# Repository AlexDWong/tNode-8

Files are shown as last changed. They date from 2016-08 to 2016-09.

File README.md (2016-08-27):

# tNode-8

The tNode-8 is an 8-universe ArtNet to DMX output node powered by a Texas Instruments Tiva-C microprocessor (TM4C1294NCPDT) and is currently in development. 

##Features

The tNode-8 is expected to include the following features:
* 8 DMX512 outputs
  * All outputs fused and optically and electrically isolated
  * Full RS485/DMX512 compliance
  * Screw terminals enabling end-user selection of 3-pin or 5-pin connectors
  * Individual universe assignment on each output
* 10/100Mbps Ethernet connectivity
* LCD character display and user input for settings adjustment
* 19"/1U rackmount enclousre
* PowerCON In/Thru
  * Auto-ranging power supply (100-240V, 50/60Hz)   
  * Input fuse

Potential features for future revisions may include (but are not limited to):
* DMX input capability
* Remote Device Management (RDM)
* Remote node configuration (LAN-based)
* Physical lockout switch
* Expansion to 16 universes of DMX I/O

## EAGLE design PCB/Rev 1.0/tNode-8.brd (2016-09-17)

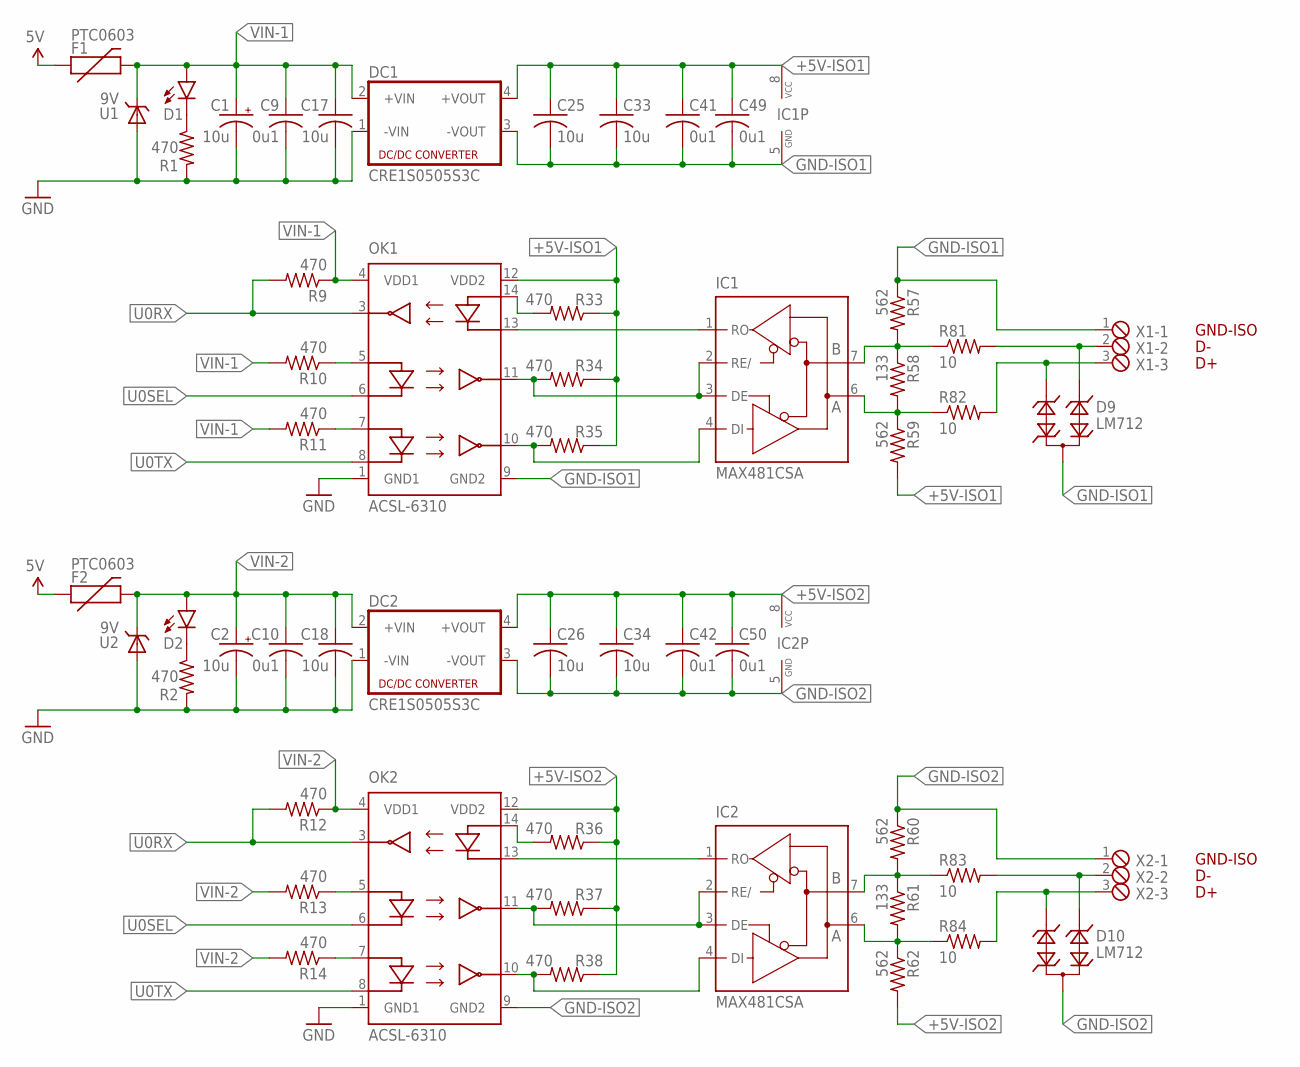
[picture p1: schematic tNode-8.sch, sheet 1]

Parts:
C1, C2: 10u; E2,5-5-NOSILK
C9, C10, C41, C42, C49, C50: 0u1; C0603K
C17, C18, C25, C26, C33, C34: 10u; C0603K
D1, D2: LED0603; LED-0603
D9, D10: LM712; SOT23
DC1, DC2: CRE1S0505S3C; 4SIL
F1, F2: PTC0603; 0603
IC1, IC2: MAX481CSA; SO08
OK1, OK2: ACSL-6310; SO-16
R1, R2, R9, R10, R11, R12, R13, R14, R33, R34, R35, R36, R37, R38: 470; R0603
R57, R59, R60, R62: 562; R0603
R58, R61: 133; R0603
R81, R82, R83, R84: 10; R0603
U1, U2: 9V; SOD323-NOSILK
X1, X2: MPT3; 3POL254

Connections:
5V: F1.1, F2.1; also elsewhere on the board
+5V-ISO1: C25.1, C33.1, C41.1, C49.1, DC1.4 (+VOUT), IC1.8 (VCC), OK1.12 (VDD2), R33.1, R34.1, R35.1, R59.2
+5V-ISO2: C26.1, C34.1, C42.1, C50.1, DC2.4 (+VOUT), IC2.8 (VCC), OK2.12 (VDD2), R36.1, R37.1, R38.1, R62.2
GND: C1.-, C2.-, C9.2, C10.2, C17.2, C18.2, DC1.1 (-VIN), DC2.1 (-VIN), OK1.1 (GND1), OK2.1 (GND1), R1.2, R2.2, U1.A, U2.A; also elsewhere on the board
GND-ISO1: C25.2, C33.2, C41.2, C49.2, D9.3, DC1.3 (-VOUT), IC1.5 (GND), OK1.9 (GND2), R57.1, X1.1
GND-ISO2: C26.2, C34.2, C42.2, C50.2, D10.3, DC2.3 (-VOUT), IC2.5 (GND), OK2.9 (GND2), R60.1, X2.1
unnamed: IC2.7 (B), R60.2, R61.1, R83.1
unnamed: IC1.7 (B), R57.2, R58.1, R81.1
unnamed: IC1.6 (A), R58.2, R59.1, R82.1
unnamed: IC2.6 (A), R61.2, R62.1, R84.1
unnamed: IC2.1 (RO), OK2.13 (C3)
unnamed: IC2.2 (RE/), IC2.3 (DE), OK2.11 (VO1), R37.2
unnamed: OK2.5 (A1), R13.1
unnamed: OK2.7 (A2), R14.1
unnamed: OK2.14 (A3), R36.2
unnamed: IC1.1 (RO), OK1.13 (C3)
unnamed: D2.C, R2.1
unnamed: D10.1, R83.2, X2.2
unnamed: D10.2, R84.2, X2.3
unnamed: IC1.2 (RE/), IC1.3 (DE), OK1.11 (VO1), R34.2
unnamed: OK1.5 (A1), R10.1
unnamed: OK1.7 (A2), R11.1
unnamed: OK1.14 (A3), R33.2
unnamed: D1.C, R1.1
unnamed: D9.1, R81.2, X1.2
unnamed: D9.2, R82.2, X1.3
OPTO-OUT1: IC1.4 (DI), OK1.10 (VO2), R35.2
OPTO-OUT2: IC2.4 (DI), OK2.10 (VO2), R38.2
U0RX: OK1.3 (V03), OK2.3 (V03), R9.2, R12.2; also elsewhere on the board
U0SEL: OK1.6 (C1), OK2.6 (C1); also elsewhere on the board
U0TX: OK1.8 (C2), OK2.8 (C2); also elsewhere on the board
VIN-1: C1.+, C9.1, C17.1, D1.A, DC1.2 (+VIN), F1.2, OK1.4 (VDD1), R9.1, R10.2, R11.2, U1.C
VIN-2: C2.+, C10.1, C18.1, D2.A, DC2.2 (+VIN), F2.2, OK2.4 (VDD1), R12.1, R13.2, R14.2, U2.C

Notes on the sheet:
GND-ISO

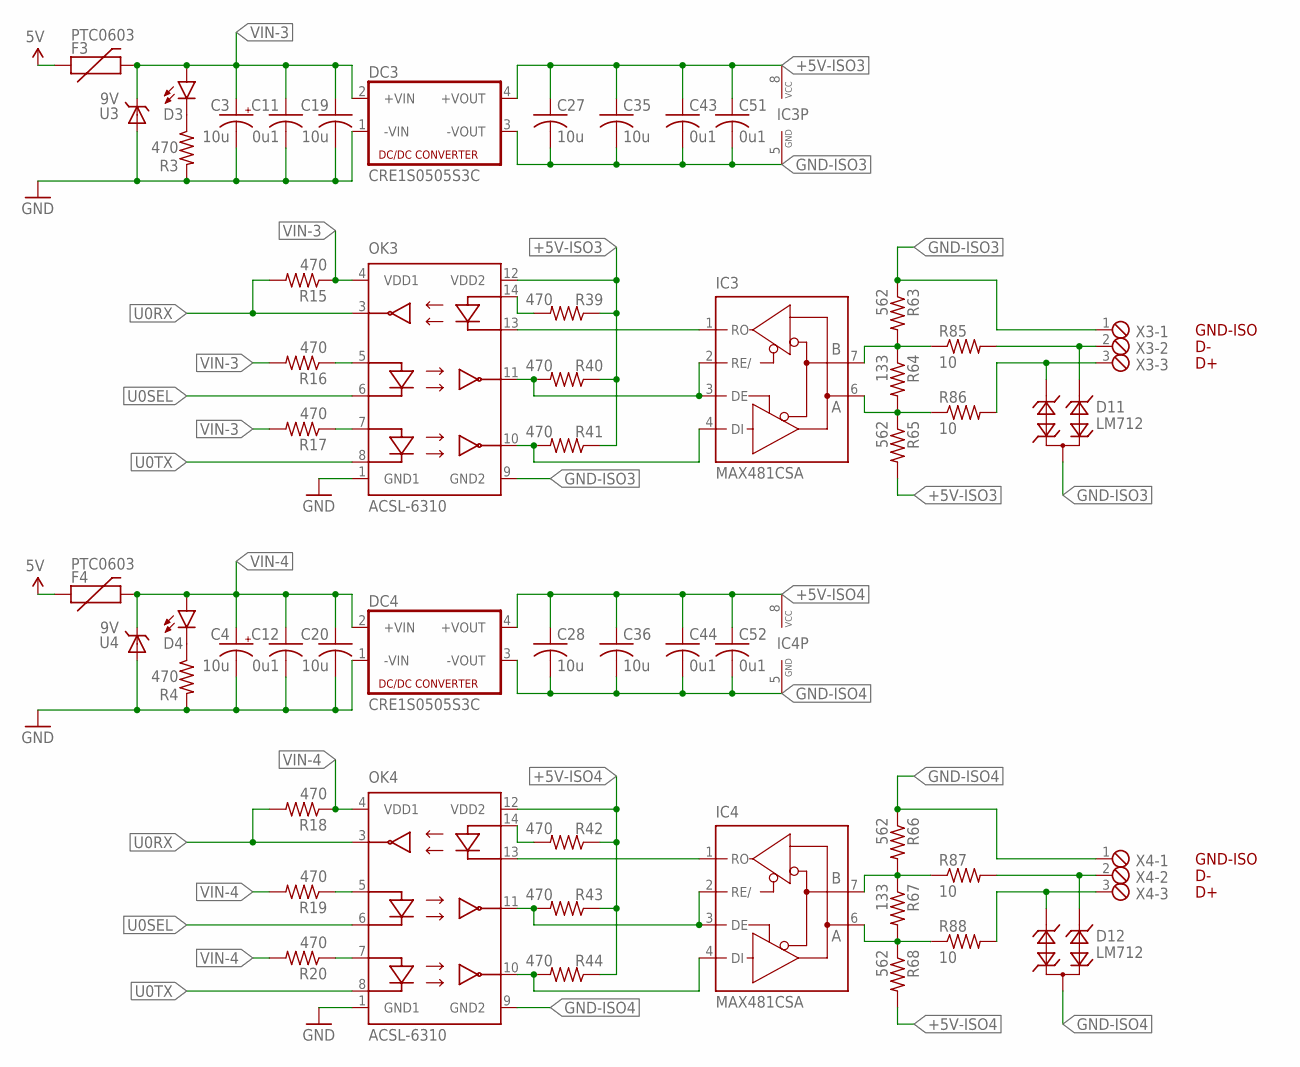
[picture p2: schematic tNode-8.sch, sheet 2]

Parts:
C3, C4: 10u; E2,5-5-NOSILK
C11, C12, C43, C44, C51, C52: 0u1; C0603K
C19, C20, C27, C28, C35, C36: 10u; C0603K
D3, D4: LED0603; LED-0603
D11, D12: LM712; SOT23
DC3, DC4: CRE1S0505S3C; 4SIL
F3, F4: PTC0603; 0603
IC3, IC4: MAX481CSA; SO08
OK3, OK4: ACSL-6310; SO-16
R3, R4, R15, R16, R17, R18, R19, R20, R39, R40, R41, R42, R43, R44: 470; R0603
R63, R65, R66, R68: 562; R0603
R64, R67: 133; R0603
R85, R86, R87, R88: 10; R0603
U3, U4: 9V; SOD323-NOSILK
X3, X4: MPT3; 3POL254

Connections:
5V: F3.1, F4.1; also elsewhere on the board
+5V-ISO3: C27.1, C35.1, C43.1, C51.1, DC3.4 (+VOUT), IC3.8 (VCC), OK3.12 (VDD2), R39.1, R40.1, R41.1, R65.2
+5V-ISO4: C28.1, C36.1, C44.1, C52.1, DC4.4 (+VOUT), IC4.8 (VCC), OK4.12 (VDD2), R42.1, R43.1, R44.1, R68.2
GND: C3.-, C4.-, C11.2, C12.2, C19.2, C20.2, DC3.1 (-VIN), DC4.1 (-VIN), OK3.1 (GND1), OK4.1 (GND1), R3.2, R4.2, U3.A, U4.A; also elsewhere on the board
GND-ISO3: C27.2, C35.2, C43.2, C51.2, D11.3, DC3.3 (-VOUT), IC3.5 (GND), OK3.9 (GND2), R63.1, X3.1
GND-ISO4: C28.2, C36.2, C44.2, C52.2, D12.3, DC4.3 (-VOUT), IC4.5 (GND), OK4.9 (GND2), R66.1, X4.1
unnamed: IC3.7 (B), R63.2, R64.1, R85.1
unnamed: IC3.6 (A), R64.2, R65.1, R86.1
unnamed: IC3.1 (RO), OK3.13 (C3)
unnamed: IC3.2 (RE/), IC3.3 (DE), OK3.11 (VO1), R40.2
unnamed: OK3.5 (A1), R16.1
unnamed: OK3.7 (A2), R17.1
unnamed: OK3.14 (A3), R39.2
unnamed: D3.C, R3.1
unnamed: D11.1, R85.2, X3.2
unnamed: D11.2, R86.2, X3.3
unnamed: IC4.7 (B), R66.2, R67.1, R87.1
unnamed: IC4.6 (A), R67.2, R68.1, R88.1
unnamed: IC4.1 (RO), OK4.13 (C3)
unnamed: IC4.2 (RE/), IC4.3 (DE), OK4.11 (VO1), R43.2
unnamed: OK4.5 (A1), R19.1
unnamed: OK4.7 (A2), R20.1
unnamed: OK4.14 (A3), R42.2
unnamed: D4.C, R4.1
unnamed: D12.1, R87.2, X4.2
unnamed: D12.2, R88.2, X4.3
OPTO-OUT3: IC3.4 (DI), OK3.10 (VO2), R41.2
OPTO-OUT4: IC4.4 (DI), OK4.10 (VO2), R44.2
U0RX: OK3.3 (V03), OK4.3 (V03), R15.2, R18.2; also elsewhere on the board
U0SEL: OK3.6 (C1), OK4.6 (C1); also elsewhere on the board
U0TX: OK3.8 (C2), OK4.8 (C2); also elsewhere on the board
VIN-3: C3.+, C11.1, C19.1, D3.A, DC3.2 (+VIN), F3.2, OK3.4 (VDD1), R15.1, R16.2, R17.2, U3.C
VIN-4: C4.+, C12.1, C20.1, D4.A, DC4.2 (+VIN), F4.2, OK4.4 (VDD1), R18.1, R19.2, R20.2, U4.C

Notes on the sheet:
GND-ISO

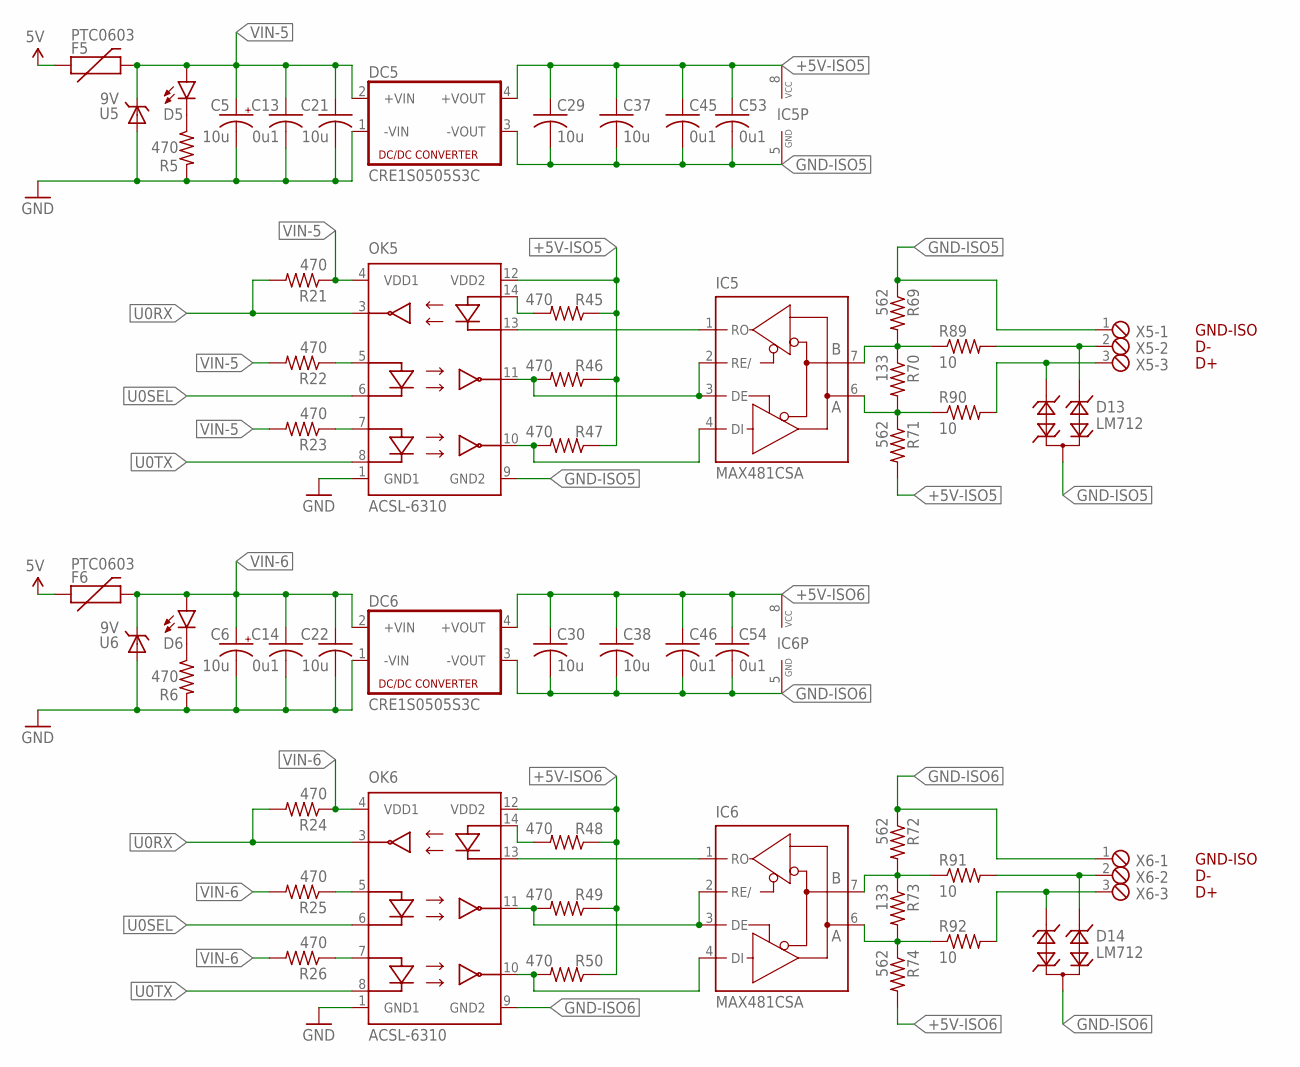
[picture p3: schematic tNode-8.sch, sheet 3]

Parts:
C5, C6: 10u; E2,5-5-NOSILK
C13, C14, C45, C46, C53, C54: 0u1; C0603K
C21, C22, C29, C30, C37, C38: 10u; C0603K
D5, D6: LED0603; LED-0603
D13, D14: LM712; SOT23
DC5, DC6: CRE1S0505S3C; 4SIL
F5, F6: PTC0603; 0603
IC5, IC6: MAX481CSA; SO08
OK5, OK6: ACSL-6310; SO-16
R5, R6, R21, R22, R23, R24, R25, R26, R45, R46, R47, R48, R49, R50: 470; R0603
R69, R71, R72, R74: 562; R0603
R70, R73: 133; R0603
R89, R90, R91, R92: 10; R0603
U5, U6: 9V; SOD323-NOSILK
X5, X6: MPT3; 3POL254

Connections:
5V: F5.1, F6.1; also elsewhere on the board
+5V-ISO5: C29.1, C37.1, C45.1, C53.1, DC5.4 (+VOUT), IC5.8 (VCC), OK5.12 (VDD2), R45.1, R46.1, R47.1, R71.2
+5V-ISO6: C30.1, C38.1, C46.1, C54.1, DC6.4 (+VOUT), IC6.8 (VCC), OK6.12 (VDD2), R48.1, R49.1, R50.1, R74.2
GND: C5.-, C6.-, C13.2, C14.2, C21.2, C22.2, DC5.1 (-VIN), DC6.1 (-VIN), OK5.1 (GND1), OK6.1 (GND1), R5.2, R6.2, U5.A, U6.A; also elsewhere on the board
GND-ISO5: C29.2, C37.2, C45.2, C53.2, D13.3, DC5.3 (-VOUT), IC5.5 (GND), OK5.9 (GND2), R69.1, X5.1
GND-ISO6: C30.2, C38.2, C46.2, C54.2, D14.3, DC6.3 (-VOUT), IC6.5 (GND), OK6.9 (GND2), R72.1, X6.1
unnamed: IC5.7 (B), R69.2, R70.1, R89.1
unnamed: IC5.6 (A), R70.2, R71.1, R90.1
unnamed: IC5.1 (RO), OK5.13 (C3)
unnamed: IC5.2 (RE/), IC5.3 (DE), OK5.11 (VO1), R46.2
unnamed: OK5.5 (A1), R22.1
unnamed: OK5.7 (A2), R23.1
unnamed: OK5.14 (A3), R45.2
unnamed: D5.C, R5.1
unnamed: D13.1, R89.2, X5.2
unnamed: D13.2, R90.2, X5.3
unnamed: IC6.7 (B), R72.2, R73.1, R91.1
unnamed: IC6.6 (A), R73.2, R74.1, R92.1
unnamed: IC6.1 (RO), OK6.13 (C3)
unnamed: IC6.2 (RE/), IC6.3 (DE), OK6.11 (VO1), R49.2
unnamed: OK6.5 (A1), R25.1
unnamed: OK6.7 (A2), R26.1
unnamed: OK6.14 (A3), R48.2
unnamed: D6.C, R6.1
unnamed: D14.1, R91.2, X6.2
unnamed: D14.2, R92.2, X6.3
OPTO-OUT5: IC5.4 (DI), OK5.10 (VO2), R47.2
OPTO-OUT6: IC6.4 (DI), OK6.10 (VO2), R50.2
U0RX: OK5.3 (V03), OK6.3 (V03), R21.2, R24.2; also elsewhere on the board
U0SEL: OK5.6 (C1), OK6.6 (C1); also elsewhere on the board
U0TX: OK5.8 (C2), OK6.8 (C2); also elsewhere on the board
VIN-5: C5.+, C13.1, C21.1, D5.A, DC5.2 (+VIN), F5.2, OK5.4 (VDD1), R21.1, R22.2, R23.2, U5.C
VIN-6: C6.+, C14.1, C22.1, D6.A, DC6.2 (+VIN), F6.2, OK6.4 (VDD1), R24.1, R25.2, R26.2, U6.C

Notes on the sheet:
GND-ISO

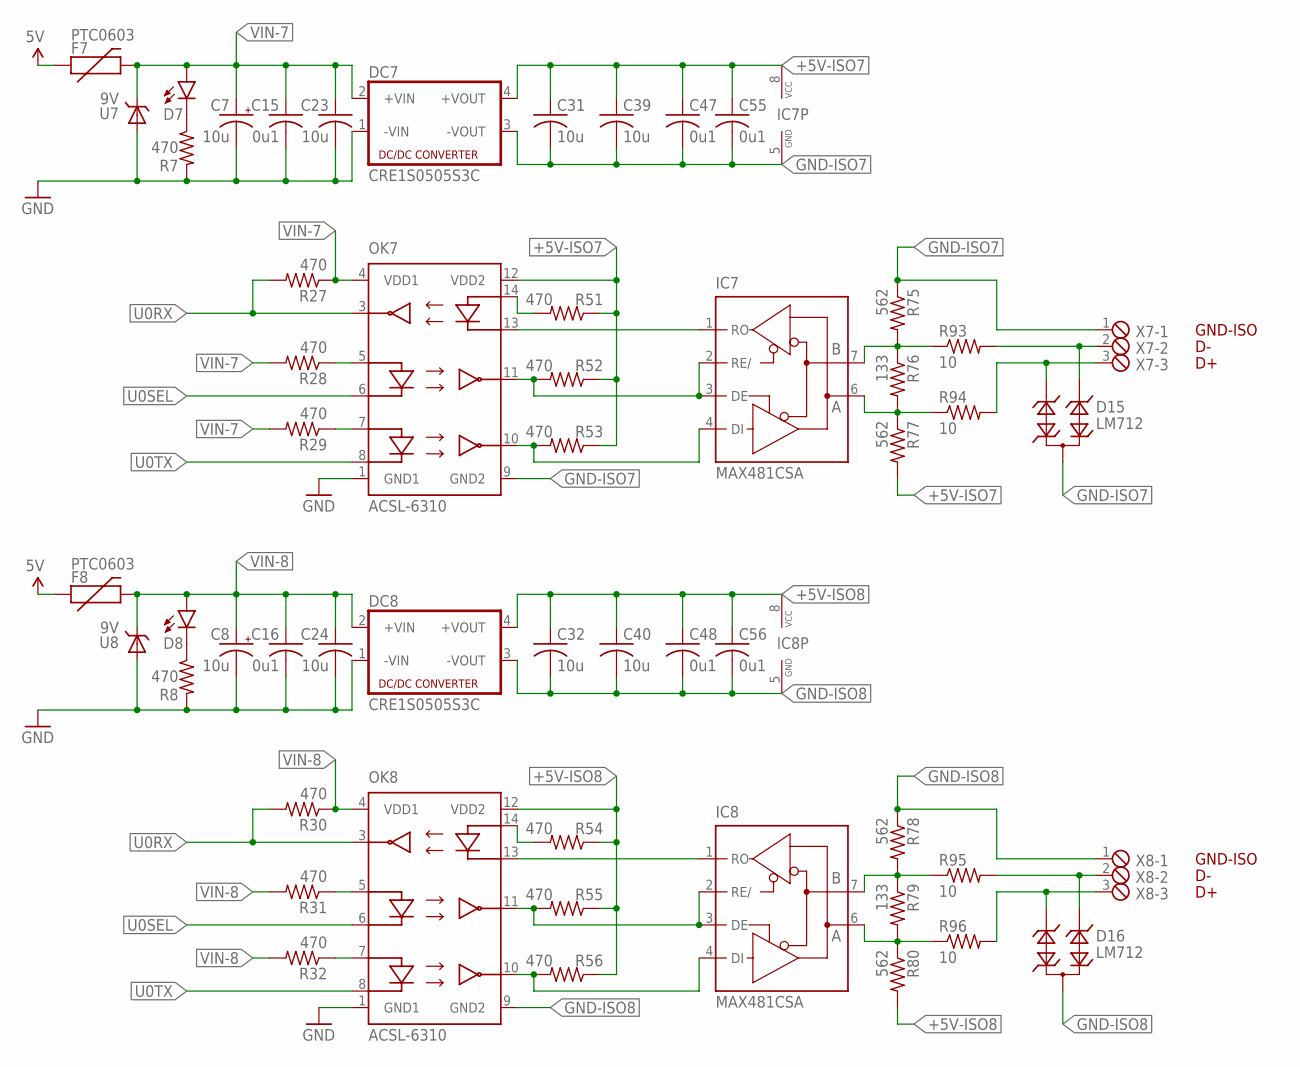
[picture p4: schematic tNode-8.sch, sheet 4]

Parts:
C7, C8: 10u; E2,5-5-NOSILK
C15, C16, C47, C48, C55, C56: 0u1; C0603K
C23, C24, C31, C32, C39, C40: 10u; C0603K
D7, D8: LED0603; LED-0603
D15, D16: LM712; SOT23
DC7, DC8: CRE1S0505S3C; 4SIL
F7, F8: PTC0603; 0603
IC7, IC8: MAX481CSA; SO08
OK7, OK8: ACSL-6310; SO-16
R7, R8, R27, R28, R29, R30, R31, R32, R51, R52, R53, R54, R55, R56: 470; R0603
R75, R77, R78, R80: 562; R0603
R76, R79: 133; R0603
R93, R94, R95, R96: 10; R0603
U7, U8: 9V; SOD323-NOSILK
X7, X8: MPT3; 3POL254

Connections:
5V: F7.1, F8.1; also elsewhere on the board
+5V-ISO7: C31.1, C39.1, C47.1, C55.1, DC7.4 (+VOUT), IC7.8 (VCC), OK7.12 (VDD2), R51.1, R52.1, R53.1, R77.2
+5V-ISO8: C32.1, C40.1, C48.1, C56.1, DC8.4 (+VOUT), IC8.8 (VCC), OK8.12 (VDD2), R54.1, R55.1, R56.1, R80.2
GND: C7.-, C8.-, C15.2, C16.2, C23.2, C24.2, DC7.1 (-VIN), DC8.1 (-VIN), OK7.1 (GND1), OK8.1 (GND1), R7.2, R8.2, U7.A, U8.A; also elsewhere on the board
GND-ISO7: C31.2, C39.2, C47.2, C55.2, D15.3, DC7.3 (-VOUT), IC7.5 (GND), OK7.9 (GND2), R75.1, X7.1
GND-ISO8: C32.2, C40.2, C48.2, C56.2, D16.3, DC8.3 (-VOUT), IC8.5 (GND), OK8.9 (GND2), R78.1, X8.1
unnamed: IC7.7 (B), R75.2, R76.1, R93.1
unnamed: IC7.6 (A), R76.2, R77.1, R94.1
unnamed: IC7.1 (RO), OK7.13 (C3)
unnamed: IC7.2 (RE/), IC7.3 (DE), OK7.11 (VO1), R52.2
unnamed: OK7.5 (A1), R28.1
unnamed: OK7.7 (A2), R29.1
unnamed: OK7.14 (A3), R51.2
unnamed: D7.C, R7.1
unnamed: D15.1, R93.2, X7.2
unnamed: D15.2, R94.2, X7.3
unnamed: IC8.7 (B), R78.2, R79.1, R95.1
unnamed: IC8.6 (A), R79.2, R80.1, R96.1
unnamed: IC8.1 (RO), OK8.13 (C3)
unnamed: IC8.2 (RE/), IC8.3 (DE), OK8.11 (VO1), R55.2
unnamed: OK8.5 (A1), R31.1
unnamed: OK8.7 (A2), R32.1
unnamed: OK8.14 (A3), R54.2
unnamed: D8.C, R8.1
unnamed: D16.1, R95.2, X8.2
unnamed: D16.2, R96.2, X8.3
OPTO-OUT7: IC7.4 (DI), OK7.10 (VO2), R53.2
OPTO-OUT8: IC8.4 (DI), OK8.10 (VO2), R56.2
U0RX: OK7.3 (V03), OK8.3 (V03), R27.2, R30.2; also elsewhere on the board
U0SEL: OK7.6 (C1), OK8.6 (C1); also elsewhere on the board
U0TX: OK7.8 (C2), OK8.8 (C2); also elsewhere on the board
VIN-7: C7.+, C15.1, C23.1, D7.A, DC7.2 (+VIN), F7.2, OK7.4 (VDD1), R27.1, R28.2, R29.2, U7.C
VIN-8: C8.+, C16.1, C24.1, D8.A, DC8.2 (+VIN), F8.2, OK8.4 (VDD1), R30.1, R31.2, R32.2, U8.C

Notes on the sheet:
GND-ISO

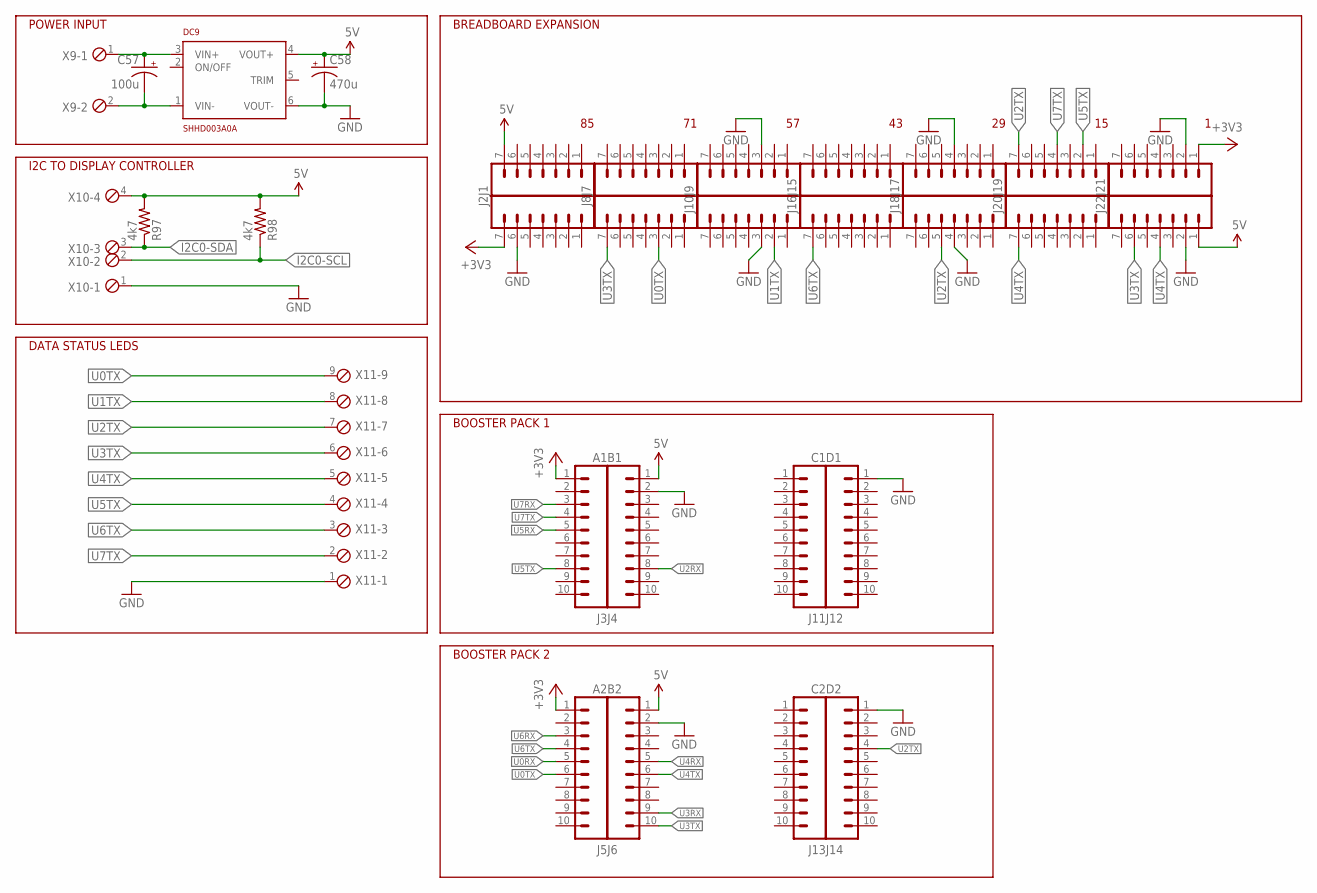
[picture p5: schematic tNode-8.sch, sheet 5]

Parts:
C57: 100u; PANASONIC_D
C58: 470u; PANASONIC_D
DC9: SHHD003A0A
J1, J2, J7, J8, J9, J10, J15, J16, J17, J18, J19, J20, J21, J22: M07; 1X07
J3: A1; 1X10
J4: B1; 1X10
J5: A2; 1X10
J6: B2; 1X10
J11: C1; 1X10
J12: D1; 1X10
J13: C2; 1X10
J14: D2; 1X10
R97, R98: 4k7; R0603
X9: MPT2; 2POL254
X10: MPT4; 4POL254
X11: MPT9; 9POL254

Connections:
5V: C58.+, DC9.4 (VOUT+), J1.7, J4.1, J6.1, J22.1, R97.2, R98.2, X10.4; also elsewhere on the board
+3V3: J2.7, J3.1, J5.1, J21.1
GND: C58.-, DC9.6 (VOUT-), J2.6, J4.2, J6.2, J9.3, J10.3, J12.1, J14.1, J17.4, J18.4, J21.2, J22.2, X10.1, X11.1; also elsewhere on the board
I2C0-SCL: R98.1, X10.2
I2C0-SDA: R97.1, X10.3
unnamed: C57.-, DC9.1 (VIN-), X9.2
unnamed: C57.+, DC9.3 (VIN+), X9.1
U0RX: J5.5; also elsewhere on the board
U0TX: J5.6, J8.3, X11.9; also elsewhere on the board
U1TX: J10.2, X11.8
U2RX: J4.8
U2TX: J14.4, J18.5, J19.7, X11.7
U3RX: J6.9
U3TX: J6.10, J8.7, J22.6, X11.6
U4RX: J6.5
U4TX: J6.6, J20.7, J22.4, X11.5
U5RX: J3.5
U5TX: J3.8, J19.2, X11.4
U6RX: J5.3
U6TX: J5.4, J16.7, X11.3
U7RX: J3.3
U7TX: J3.4, J19.4, X11.2

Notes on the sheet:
POWER INPUT
BOOSTER PACK 1
BOOSTER PACK 2
BREADBOARD EXPANSION
I2C TO DISPLAY CONTROLLER
DATA STATUS LEDS

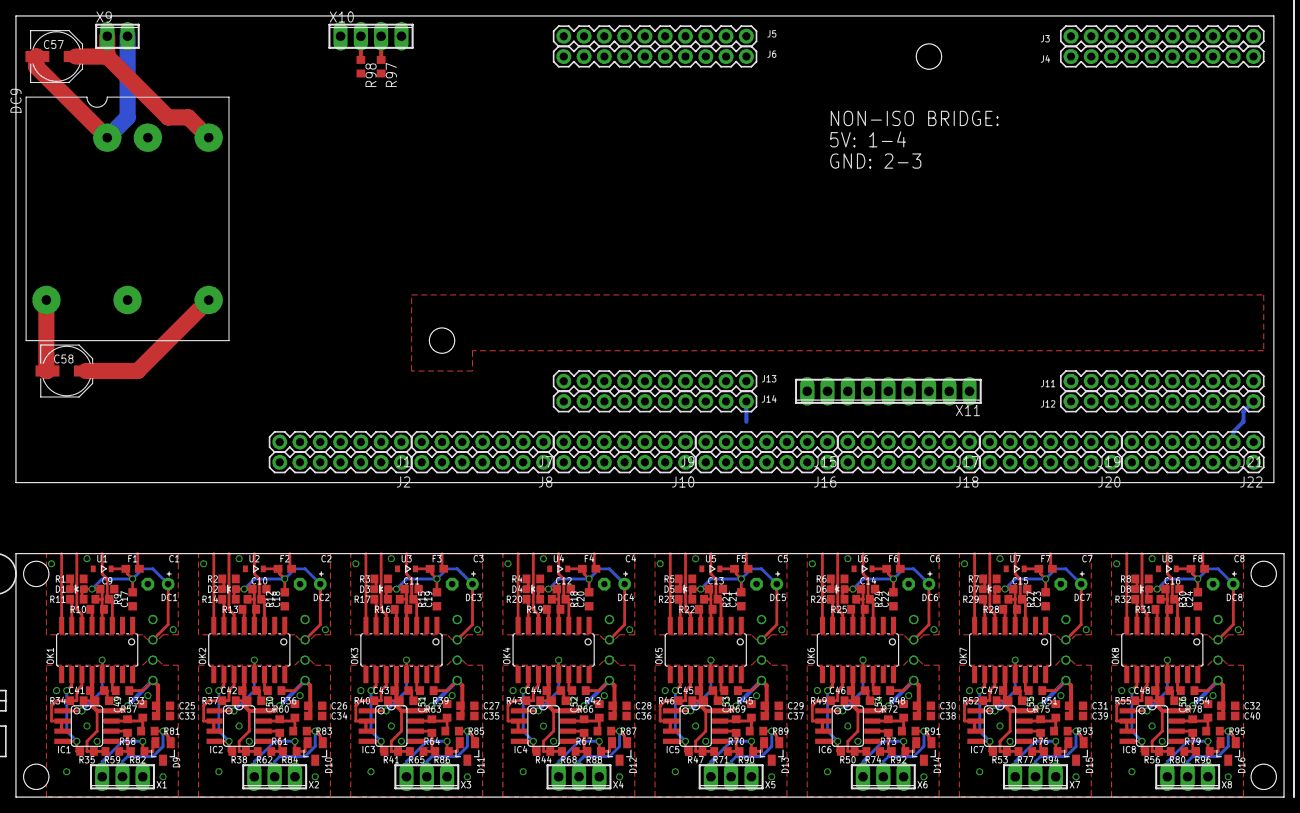
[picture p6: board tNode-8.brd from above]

Board: 2 copper layers, 158.8 x 30.5 mm, 246 parts (0 on the bottom side), 129 nets.

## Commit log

2016-09-17 [WIP] PCB Rev 1.0
    [tNode-8.brd, tNode-8.sch]
2016-09-17 [WIP] add all UART-DMX outputs
    [tNode-8.brd, tNode-8.sch]

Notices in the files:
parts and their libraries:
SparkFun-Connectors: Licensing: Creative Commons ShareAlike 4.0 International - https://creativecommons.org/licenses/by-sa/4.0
